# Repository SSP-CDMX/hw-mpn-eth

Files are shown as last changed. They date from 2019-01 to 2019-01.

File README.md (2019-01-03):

# Plataforma Mi Policía en Mi Negocio - Ethernet
Hardware MPN Ethernet

La plataforma  **Mi Policía en Mi Negocio** es un grupo de tecnologías aplicadas para la prevención e inhibición del delito, tecnologías que definen una red de alarmas silenciosas activadas mediante dispositivos móviles o electrónicos comunicadas por Internet.

Esta plataforma consta de una parte pública y una parte controlada y administrada exclusivamente por la Policía de la Ciudad de México, por lo tanto **todos** los servicios que ofrece la plataforma son totalmente **gratuitos**.

La parte controlada es una base de datos georeferenciada de los negocios afiliados y sus sucursales, a fin de brindar una URL que permite disparar una llamada de alerta en la infraestructura privada de la Policía, a fin de poder despachar la patrulla mas cercana.

Si usted desea registrar su negocio le sugerimos llenar el [formulario de pre-registro. ](http://mipolicia.ssp.cdmx.gob.mx/mpn/preafiliacion)

Lo que hay en este repositorio es la parte pública. 

Esta parte pública se libera bajo licencia **Atribución-CompartirIgual 2.5 México  (CC BY-SA 2.5 MX)**, al tratarse de un derivado de la plataforma **Arduino**, por lo tanto, lo que encontrará aquí son las especificaciones para armar su propio circuito **DIY-MiPolicia**, exactamente como el que obtendría al asistir a los talleres que imparte la Policía de la Ciudad de México.

## Cómo se arma
Puedes armar el circuito de Mi Policia muy fácilmente, en tu casa, con componentes fáciles de obtener, ...

## Lista de materiales básica
Esta lista contiene los componentes mínimos necesarios para armar el módulo mínimo de Mi Policía

|  Cantidad |Descripción |Referencia gráfica |
|---|---|---|
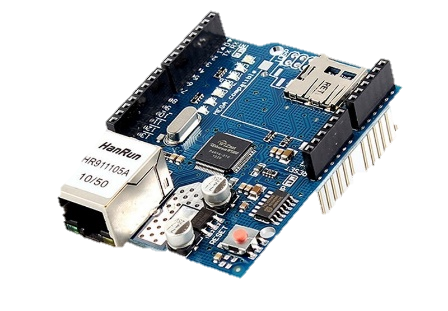
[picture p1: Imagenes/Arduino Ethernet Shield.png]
Arduino Ethernet Shield
|1|Shield Ethernet para Arduino |  |
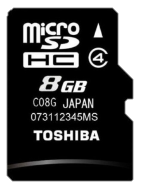
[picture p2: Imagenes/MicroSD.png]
Micro SD 8 Gb
|1|Tarjeta Micro SD 8Gb | |
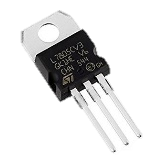
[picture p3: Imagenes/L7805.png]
Regulador L7805
|1|Regulador de Voltaje L7805 5v||
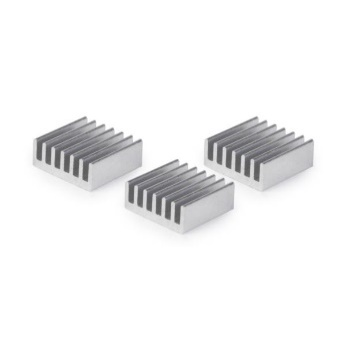
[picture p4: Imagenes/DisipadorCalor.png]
Disipador de Calor
|1|Disipador de Calor 8x8x5 mm||
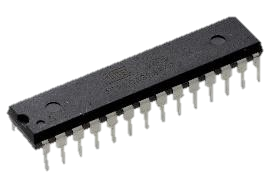
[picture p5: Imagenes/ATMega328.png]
ATMega 328
|1|Micro controlador ATMEGA 328 ||
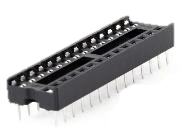
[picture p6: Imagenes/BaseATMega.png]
Base para Micro controlador
|1|Base para Micro controlador ATMEGA 328 (28 pines) ||
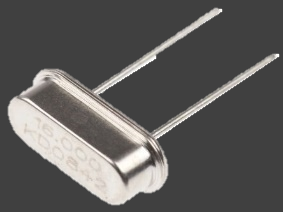
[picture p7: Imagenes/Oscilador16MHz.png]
Cristal oscilador 16 MHz
|1|Cristal oscilador 16 MHz||
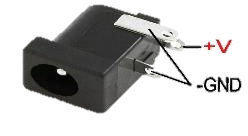
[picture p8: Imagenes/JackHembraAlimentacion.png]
Conector Jack hembra
|1|Conector Jack hembra, alimentación debe conicidir con la entrada de la fuente de alimentación||
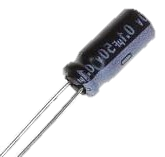
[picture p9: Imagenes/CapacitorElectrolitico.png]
Capacitor Electrolítico
|1|Capacitor Electrolítico 0.1  $\mu$Farad a 50 volts||
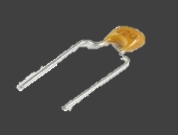
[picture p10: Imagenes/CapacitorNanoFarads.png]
Capacitor 100 nano Faradios
|1|Capacitor 100 nano Faradios||
|2|Capacitor 22 pico Faradios|Capacitor 22 pico Faradios|
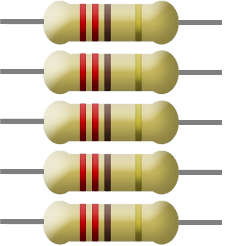
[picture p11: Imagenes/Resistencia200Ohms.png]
Resistencia de Carbón 220 Ohms
|5|Resistencia de Carbón 220 $\Omega$  1/2 Watt||
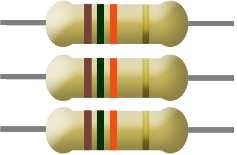
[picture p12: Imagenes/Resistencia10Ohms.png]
Resistencia de Carbón 10 KOhms
|5|Resistencia de Carbón 10 K$\Omega$  1/2 Watt||
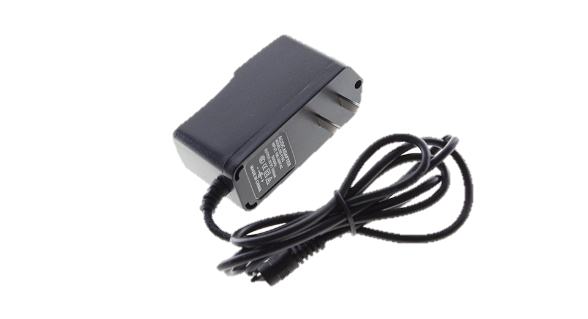
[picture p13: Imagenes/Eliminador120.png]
Eliminador 120V - 9V
|1|Eliminador 120 - 9 VCD 0.850mA o 1 A con entrada para Jack hembra alimentación ||
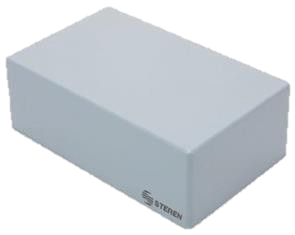
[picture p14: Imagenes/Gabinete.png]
Gabinete de plástico
|1|Gabinete de plástico con tapa, de 15x9x6 cm aproximadamente||
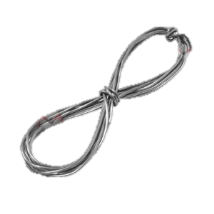
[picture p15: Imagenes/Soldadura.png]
Soldadura de Estaño
|1| 1 metro de soldadura de estaño||
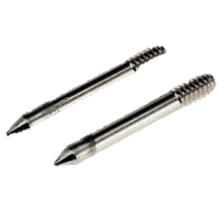
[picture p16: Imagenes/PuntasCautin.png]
Puntas para cautín
|2| Puntas para cautín Weller de 23 o 25W||
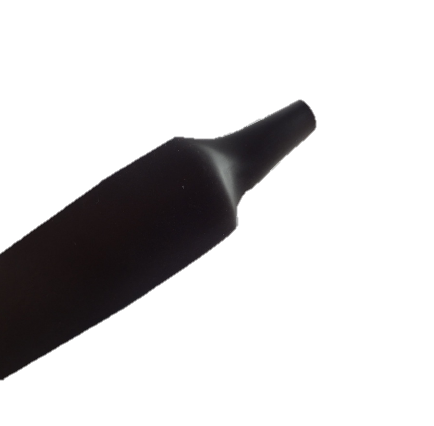
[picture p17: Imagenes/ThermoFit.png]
Metro de tubo Thermofit
|1| Metro de tubo Thermofit de 1 mm de diámetro||
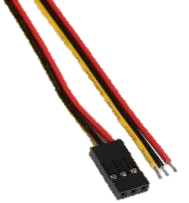
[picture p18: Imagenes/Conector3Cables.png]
Tira de Conector de tres cables
|4| Tira de Conector de tres cables||
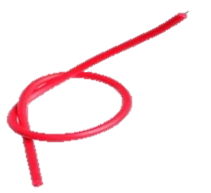
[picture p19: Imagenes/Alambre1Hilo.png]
Alambre de 1 hilo para conectar circuitos electrónicos
|1|Metro de Alambre de 1 hilo para conectar circuitos electrónicos ||
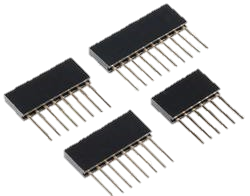
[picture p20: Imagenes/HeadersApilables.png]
Paquete con 4 tiras de Headers apilables para nuevos modelos Arduino
|1|Paquete con 4 tiras de Headers apilables para nuevos modelos Arduino ||
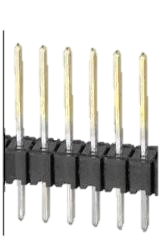
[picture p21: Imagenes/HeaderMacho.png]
Tira sencilla de 36 Header macho
|1|Tira sencilla de 36 Header macho ||
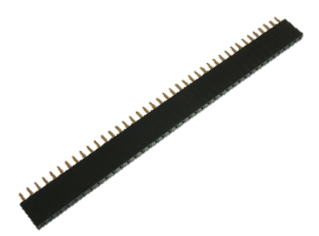
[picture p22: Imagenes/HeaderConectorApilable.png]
Tira de header y conector apilable
|2|Tira de header y conector apilable||
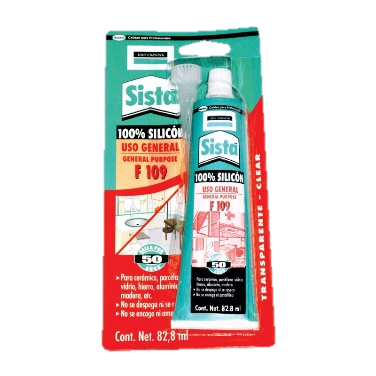
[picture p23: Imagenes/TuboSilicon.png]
Tubo de Silicón Frío
|1|Tubo de Silicón Frío||
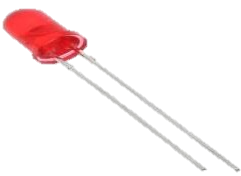
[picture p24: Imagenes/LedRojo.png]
Diodo Led Rojo
|1|Diodo Led Rojo | |
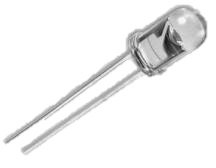
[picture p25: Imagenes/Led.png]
Diodo Led Verde
|1|Diodo Led Verde||
|1|Diodo Led Azul|Diodo Led Azul|
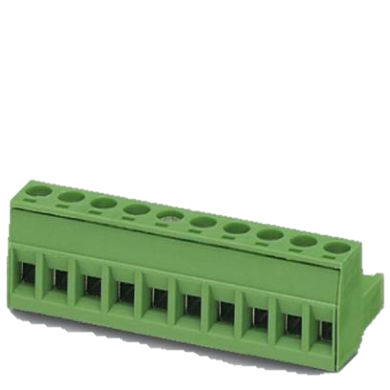
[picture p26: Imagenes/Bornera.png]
Bornera de Audio con 9 terminales
|1|Bornera de Audio con 9 terminales ||
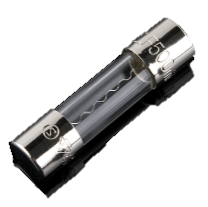
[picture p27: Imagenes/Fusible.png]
Fusible F500L 500 miliAmperes (5x20mm)
|1|Fusible F500L 500 miliAmperes (5x20mm)||
|2|Porta fusible F500L (5x20mm)|Porta fusible F500L (5x20mm)|

## Lista de materiales extendida
Esta lista contiene los accesorios necesarios para los diferentes modos electrónicos de activación.

 - Botón físico
 - Botón inalámbrico
 - Alarma propia (cuando ya se invirtió en una alarma propia)
 - Sensor magnético
 - Sensor de movimiento

|  Cantidad |Descripción |Referencia gráfica |
|---|---|---|
|1|Botón físico| Botón físico
|1|Receptor simple de RF M4-315 MHz|Receptor simple de RF |
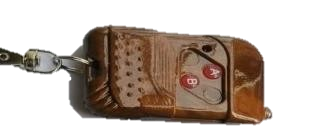
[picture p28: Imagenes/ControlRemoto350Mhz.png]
Control remoto RF Tipo llavero 305 MHz
|1|Control remoto RF Tipo llavero 305 MHz| |
|1|Relevador 12v CD (Para un funcionamiento óptimo, deberá ser tal cual se muestra en la imagen)| 
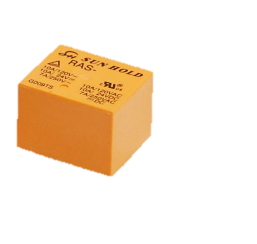
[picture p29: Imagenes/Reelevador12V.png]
Relevador 12v CD
|1|Sensor magnético||
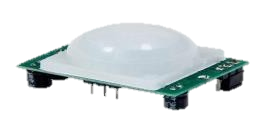
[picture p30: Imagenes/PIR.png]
PIR HC-SR501
|1|Sensor PIR HC-SR501||

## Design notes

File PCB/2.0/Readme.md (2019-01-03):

El circuito impreso se hizo con Eagle http://www.autodesk.com/education/free-software/eagle.
Usa ese software para abrir los archivos .sch o .brd, con él podrás hacer modificaciones a la placa.
Puedes usar el archivo Gerber.zip para cargarlo a un servicio de creación de PCB (Printed Circuit Boards), por ejemplo:

http://www.smart-prototyping.com/PCB-Prototyping.html

https://jlcpcb.com/

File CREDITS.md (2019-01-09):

# Plataforma Mi Policía

## Secretaría de Seguridad Pública de la Ciudad de México

**Idea original:**

 Maestro Jaime Pedro Ibarra Díaz-Trujillo
 
**Ingeniería Electrónica y Programación:** 

Doctor Alberto Morales Varela

Maestro Enrique Granados Andrade

Ingeniero Esteban Ramírez Tamayo

Ingeniero Armando Velasco Jiménez

Ingeniero Enrique Castillo Valencia

Ingeniero Jonathan Rodolfo de la O de la O

Ingeniero José Gilberto Colín Velasco

Ingeniero Alonso Morales Hernández

**Promoción:** 

Maestra Noemi Torrez Rubio

Licenciado Ivan Cruz Hernández 

Licenciado Irving Oswaldo Lázaro Moreno

Licenciado Luis Orlando Luna Ramírez

Licenciada Blanca Estela Salazar Bernal

Licenciada Karen Francisco Severiano

Licenciada Ana Cecilia Huerta Hernández

Ingeniero Brandon David Vivas Espinosa

Ingeniero Arturo Frappé Muñoz

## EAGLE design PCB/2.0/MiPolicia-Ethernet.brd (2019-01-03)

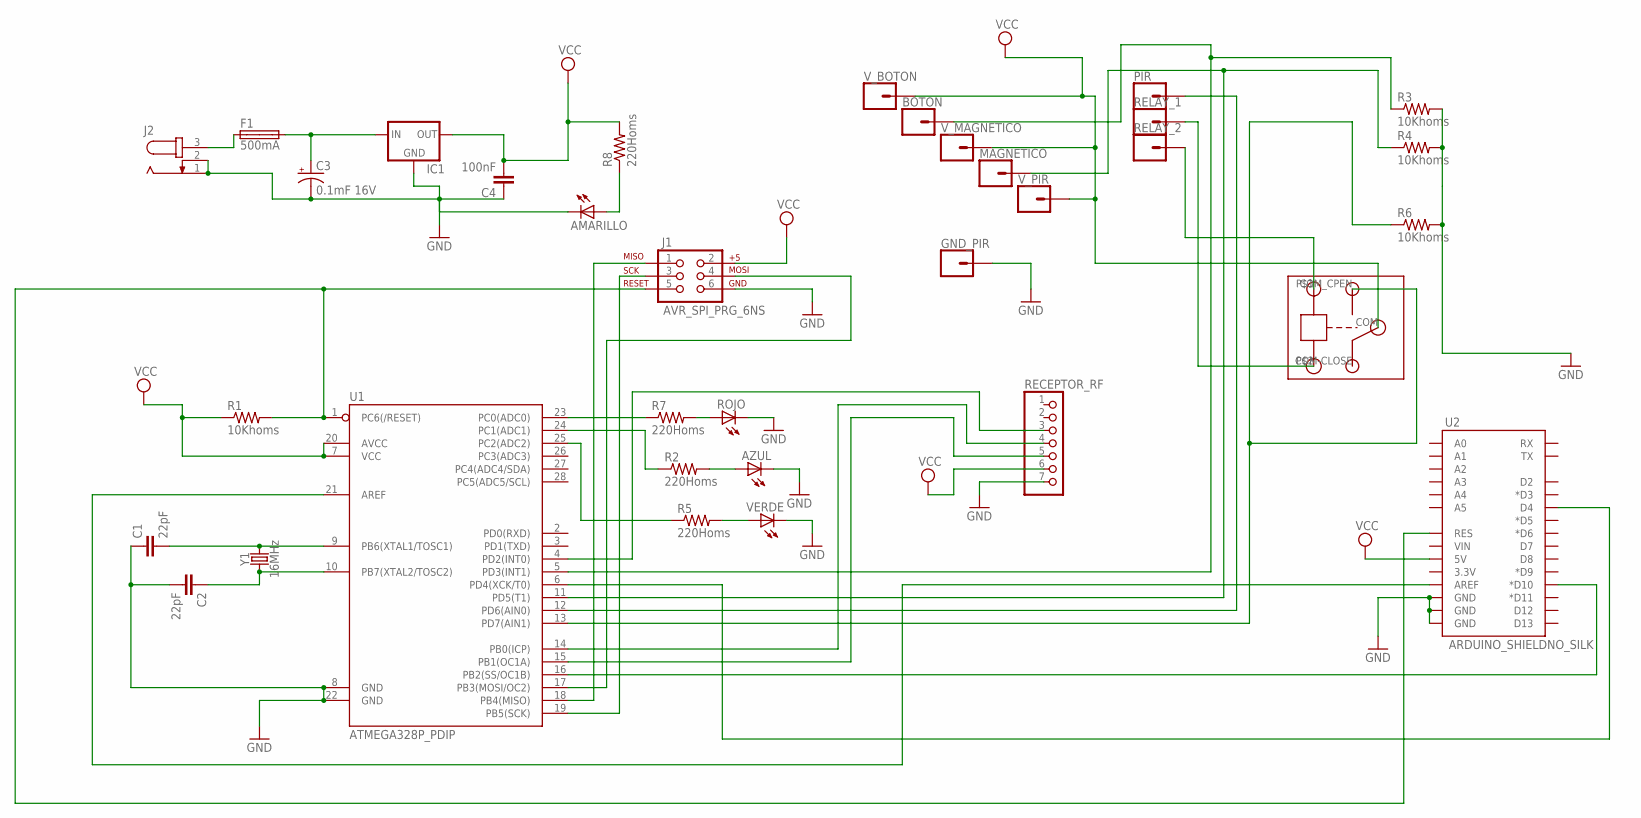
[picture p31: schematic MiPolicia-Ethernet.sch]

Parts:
AMARILLO: LED5MM
AZUL: LED5MM
BOTON: CONN_01; 1X01
C1, C2: 22pF; CAP-PTH-2.54
C3: 0.1mF 16V; CPOL-RADIAL-2.5MM-5MM-KIT
C4: 100nF; CAP-PTH-2.54
F1: 500mA; SHK20L
GND_PIR: CONN_01; 1X01
IC1: V_REG_78XXSINK; TO220-IGO
J1: AVR_SPI_PRG_6NS; 2X3-NS
J2: JACK-PLUG0; SPC4077
MAGNETICO: CONN_01; 1X01
PIR: CONN_01; 1X01
R1, R3, R4, R6: 10Khoms; AXIAL-0.4
R2, R5, R7, R8: 220Homs; AXIAL-0.4
RECEPTOR_RF: PINHD-1X7; 1X07
RELAY_1, RELAY_2: CONN_01; 1X01
ROJO: LED5MM
U1: ATMEGA328P_PDIP; DIL28-3
U2: ARDUINO_SHIELDNO_SILK; DUEMILANOVE_VIAS
U$1: RELAY
VERDE: LED5MM
V_BOTON: CONN_01; 1X01
V_MAGNETICO: CONN_01; 1X01
V_PIR: CONN_01; 1X01
Y1: 16MHz; HC49US

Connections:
GND: AMARILLO.K (C), AZUL.K (C), C1.1, C2.2, C3.2 (-), C4.1, GND_PIR.1, IC1.GND, J1.6, J2.1, J2.2, R3.P$2 (2), R4.P$2 (2), R6.P$2 (2), RECEPTOR_RF.7, ROJO.K (C), U1.8 (GND), U1.22 (GND), U2.GND@0 (GND), U2.GND@1 (GND), U2.GND@2 (GND), VERDE.K (C)
unnamed: J1.5, R1.P$2 (2), U1.1 (PC6(/RESET)), U2.RES
unnamed: R2.P$1 (1), U1.24 (PC1(ADC1))
unnamed: F1.1A, J2.3
unnamed: C1.2, U1.9 (PB6(XTAL1/TOSC1)), Y1.2
unnamed: C2.1, U1.10 (PB7(XTAL2/TOSC2)), Y1.1
unnamed: AZUL.A, R2.P$2 (2)
unnamed: U1.6 (PD4(XCK/T0)), U2.D4
unnamed: U1.16 (PB2(SS/OC1B)), U2.D10 (*D10)
unnamed: U1.21 (AREF), U2.AREF
unnamed: J1.4, U1.17 (PB3(MOSI/OC2))
unnamed: J1.1, U1.18 (PB4(MISO))
unnamed: J1.3, U1.19 (PB5(SCK))
unnamed: MAGNETICO.1, R4.P$1 (1), U1.11 (PD5(T1))
unnamed: BOTON.1, R3.P$1 (1), U1.5 (PD3(INT1))
unnamed: PIR.1, U1.12 (PD6(AIN0))
unnamed: R5.P$1 (1), U1.25 (PC2(ADC2))
unnamed: RECEPTOR_RF.4, U1.14 (PB0(ICP))
unnamed: AMARILLO.A, R8.P$1 (1)
unnamed: RECEPTOR_RF.5, U1.15 (PB1(OC1A))
unnamed: C3.1 (+), F1.2A, IC1.IN
unnamed: RECEPTOR_RF.3, U1.4 (PD2(INT0))
unnamed: R7.P$1 (1), U1.23 (PC0(ADC0))
unnamed: R7.P$2 (2), ROJO.A
unnamed: RELAY_2.1, U$1.P$1 (IN)
unnamed: RELAY_1.1, U$1.P$2 (GND)
unnamed: R6.P$1 (1), U1.13 (PD7(AIN1)), U$1.COM_CPEN (COM-OPEN)
unnamed: R5.P$2 (2), VERDE.A
VCC: C4.2, IC1.OUT, J1.2, R1.P$1 (1), R8.P$2 (2), RECEPTOR_RF.6, U1.7 (VCC), U1.20 (AVCC), U2.5V, U$1.COM, V_BOTON.1, V_MAGNETICO.1, V_PIR.1

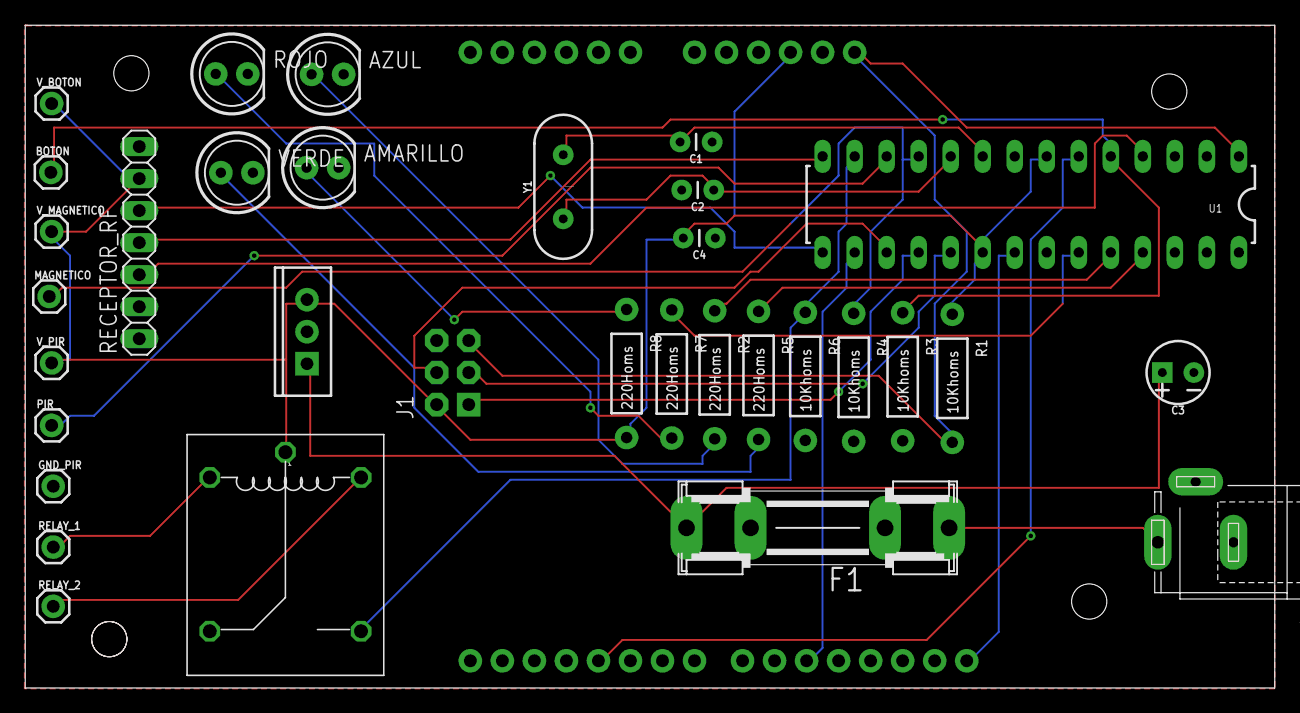
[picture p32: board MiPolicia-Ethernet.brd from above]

Board: 2 copper layers, 99.1 x 52.6 mm, 34 parts (0 on the bottom side), 29 nets.

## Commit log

2019-01-03 Imagenes lista de materiales
2019-01-03 Lista de materiales
2019-01-03 Agrega esquema del pcb
    [MiPolicia-Ethernet.brd, MiPolicia-Ethernet.sch]
2019-01-03 Establece licencia para hardware CC-by-sa/2.5/mx
2019-01-03 Cambios de nomenclatura y titulo

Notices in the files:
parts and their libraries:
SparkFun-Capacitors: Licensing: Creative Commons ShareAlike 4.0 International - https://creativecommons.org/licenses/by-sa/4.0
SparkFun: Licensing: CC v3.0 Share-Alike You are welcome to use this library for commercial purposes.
